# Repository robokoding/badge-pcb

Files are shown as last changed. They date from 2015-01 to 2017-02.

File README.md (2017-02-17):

nametag
=======

LED dot matrix name tag

bill of materials
=================
**ebay:**
* 1 x [Tilt switch](http://www.ebay.com/itm/251612655766)<br>
* 1 x [MCP73831T](http://www.ebay.com/itm/251610085563)<br>
* 2 x [SPDT slide switch](http://www.ebay.com/itm/201095465543)<br>
* 1 x [3.7V 130mAh Li-Po](http://www.ebay.com/itm/130617227476)<br>
* 1 x [3.3V 8MHz Pro Mini](http://www.ebay.com/itm/231368307663) <br>
* 1 x [HT1632C LED Driver](http://www.ebay.com/itm/251685195429) <br>
* 1 x [Micro Mini JST Connector](http://www.ebay.com/itm/271631717682161344644655)<br>

**local electronics store:**
* 1 x 2kΩ resistor
* 8 x 33Ω resistor
* 1 x 330Ω resistor
* 1 x red SMD LED
* 1 x 3V zener diode
* 3 x 4.7uF ceramic capacitor
* 1 x 4.7uF electrolytic capacitor
* some female and male pin headers

**tips:**
* instread the Pro Mini [Pro Micro](http://www.ebay.com/itm/140972980117) or [Pro Micro BLE](http://www.ebay.com/itm/251696382555) can be used

assembly instruction
====================
happy soldering ^_^

datasheets
==========
[HT1632C](http://www.adafruit.com/datasheets/ht1632cv120.pdf) <br>
[MCP73831T](https://www.sparkfun.com/datasheets/Prototyping/Batteries/MCP73831T.pdf) <br>

credits ^_^
===========
[Arduino wiring](https://learn.adafruit.com/16x24-led-matrix/wiring) <br>
[Sparkfun FIO board](https://www.sparkfun.com/products/11520) <br>
[Adafruit EAGLE library](https://github.com/adafruit/Adafruit-Eagle-Library/blob/master/adafruit.lbr) <br>
[HT1632C Arduino library](https://github.com/adafruit/HT1632) <br>
[HT1632C reference board](http://2.bp.blogspot.com/-Hhg82y6URPg/UglrFuE2HcI/AAAAAAAAALw/jM5RPzM6XEs/s1600/back.jpg) <br>
[Sparkfun EAGLE libraries](https://github.com/sparkfun/SparkFun-Eagle-Libraries) <br>
[Titlt switch istructables](http://www.instructables.com/id/Tilt-Sensor-Tutorial/step5/Reading-switch-state-with-a-microcontroller/) <br>
[hosentraeger EAGLE library](https://github.com/hosentraeger/LED-Matrix-HT1632/blob/master/ht1632.lbr) <br>
[Sparkfun USB Li-Po charger](https://www.sparkfun.com/products/10217) <br>
[Jaycon Systems USB Li-Po charger](http://www.jayconsystems.com/micro-usb-lipo-charger-mcp73831.html) <br>
[Adafuit Trinket / Gemma Space Invader Pendant](https://learn.adafruit.com/trinket-slash-gemma-space-invader-pendant/wirin) <br>

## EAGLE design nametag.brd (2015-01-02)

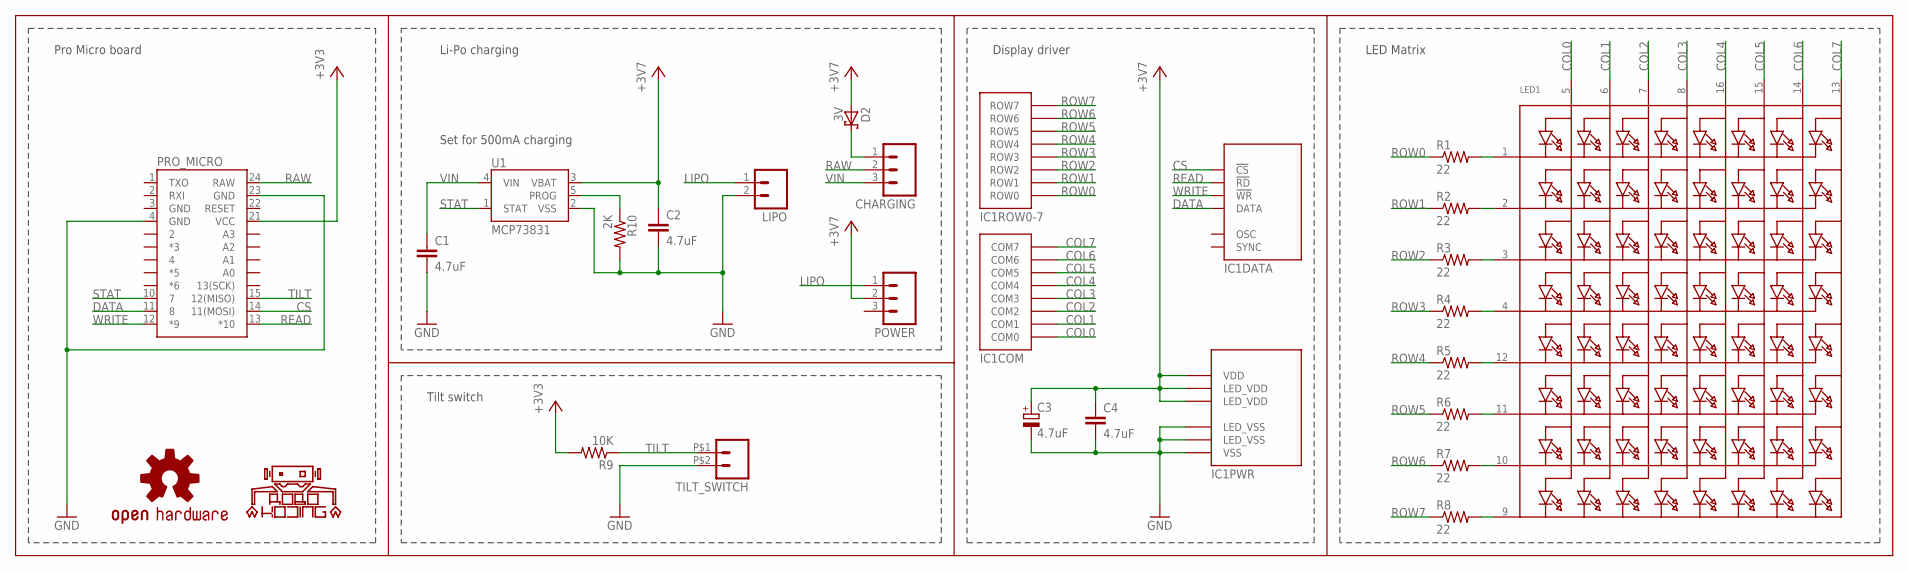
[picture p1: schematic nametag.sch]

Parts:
C1, C2, C4: 4.7uF; 0402-CAP
C3: 4.7uF; PANASONIC_B
CHARGING: M03PTH; 1X03
D2: 3V; SOD323_ST
IC1: HT1632; QFP52
LED1: SEGMENT_8X8_ROWCATHODE; SEGMENT_BL-M07C881UR
LIPO: M02JST-PTH-VERT; JST-2-PTH-VERT
LOGO1: OSHW-LOGOS; OSHW-LOGO-S
LOGO2: ROBOKODING-LOGOS; ROBOKODING-LOGO-S
POWER: M03PTH; 1X03
PRO_MICRO: ARDUINO_PRO_MICRO
R1, R2, R3, R4, R5, R6, R7, R8: 22; 0402-RES
R9: 10K; 0402-RES
R10: 2K; 0402-RES
TILT_SWITCH: M02PTH2; 1X02_BIG
U1: MCP73831; SOT23-5

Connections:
+3V3: C2.1, C3.+, C4.1, D2.A, IC1.P$7 (LED_VDD), IC1.P$21 (VDD), IC1.P$38 (LED_VDD), POWER.2, U1.3 (VBAT)
COL0: IC1.P$22 (COM0), LED1.5 (A1)
COL1: IC1.P$23 (COM1), LED1.6 (A2)
COL2: IC1.P$24 (COM2), LED1.7 (A3)
COL3: IC1.P$26 (COM3), LED1.8 (A4)
COL4: IC1.P$27 (COM4), LED1.16 (A5)
COL5: IC1.P$28 (COM5), LED1.15 (A6)
COL6: IC1.P$29 (COM6), LED1.14 (A7)
COL7: IC1.P$30 (COM7), LED1.13 (A8)
CS: IC1.P$19 (!CS), PRO_MICRO.14 (11(MOSI))
DATA: IC1.P$16 (DATA), PRO_MICRO.11 (8)
GND: C1.2, C2.2, C3.-, C4.2, IC1.P$14 (VSS), IC1.P$25 (LED_VSS), IC1.P$36 (LED_VSS), LIPO.2, PRO_MICRO.4 (GND), PRO_MICRO.23 (GND), R10.2, TILT_SWITCH.P$2 (2), U1.2 (VSS)
LIPO: LIPO.1, POWER.1
unnamed: LED1.1 (K1), R1.2
unnamed: LED1.2 (K2), R2.2
unnamed: CHARGING.1, D2.C
unnamed: LED1.3 (K3), R3.2
unnamed: LED1.4 (K4), R4.2
unnamed: LED1.12 (K5), R5.2
unnamed: LED1.11 (K6), R6.2
unnamed: LED1.10 (K7), R7.2
unnamed: LED1.9 (K8), R8.2
PROG: R10.1, U1.5 (PROG)
RAW: CHARGING.2, PRO_MICRO.24 (RAW)
READ: IC1.P$18 (!RD), PRO_MICRO.13 (*10)
ROW0: IC1.P$13 (ROW0), R1.1
ROW1: IC1.P$12 (ROW1), R2.1
ROW2: IC1.P$11 (ROW2), R3.1
ROW3: IC1.P$10 (ROW3), R4.1
ROW4: IC1.P$9 (ROW4), R5.1
ROW5: IC1.P$8 (ROW5), R6.1
ROW6: IC1.P$6 (ROW6), R7.1
ROW7: IC1.P$5 (ROW7), R8.1
STAT: PRO_MICRO.10 (7), U1.1 (STAT)
TILT: PRO_MICRO.15 (12(MISO)), R9.1, TILT_SWITCH.P$1 (1)
VCC: PRO_MICRO.21 (VCC), R9.2
VIN: C1.1, CHARGING.3, U1.4 (VIN)
WRITE: IC1.P$17 (!WR), PRO_MICRO.12 (*9)

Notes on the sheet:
Li-Po charging
Display driver
Pro Micro board
LED Matrix
Set for 500mA charging
Tilt switch

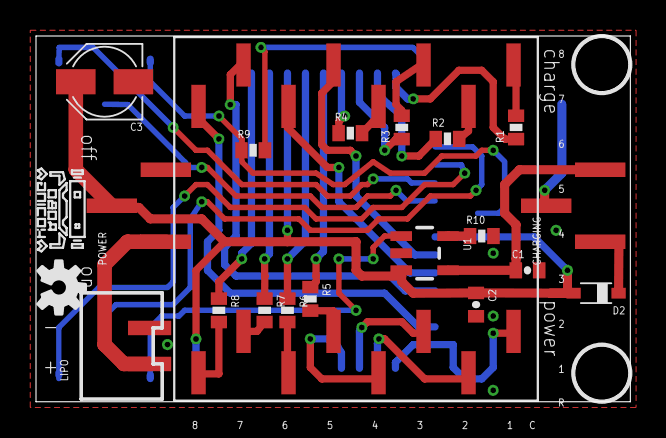
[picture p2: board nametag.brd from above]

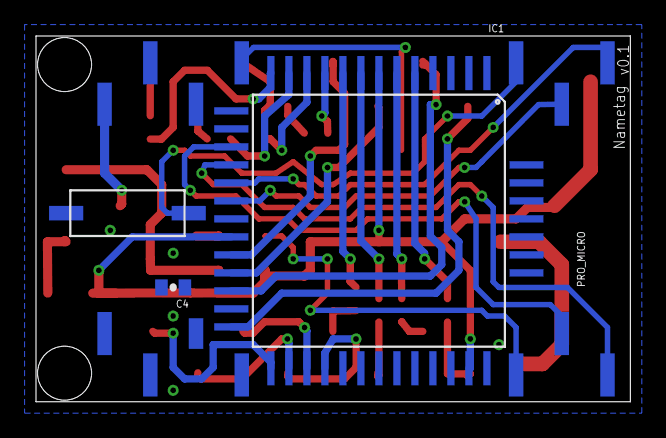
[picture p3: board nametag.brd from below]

Board: 2 copper layers, 33.0 x 20.3 mm, 27 parts (6 on the bottom side), 38 nets.

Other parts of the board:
U$1, U$2: 3,0

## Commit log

2014-11-20 added EAGLE schematics and board
    [nametag.brd, nametag.sch]
2014-11-22 separated battery and microcontroller VCC
    [nametag.sch]
2014-11-22 updated routes
    [nametag.brd]
2014-11-22 added logos
    [nametag.brd]
2014-11-22 updated logos
    [nametag.sch]
2015-01-02 updated nametag schematic and board
    [nametag.brd, nametag.sch]

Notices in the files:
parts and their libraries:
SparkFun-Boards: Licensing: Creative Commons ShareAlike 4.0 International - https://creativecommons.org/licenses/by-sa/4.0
